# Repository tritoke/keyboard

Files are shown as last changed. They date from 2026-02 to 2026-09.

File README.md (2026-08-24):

# keyboard

This is my efforts towards making the exact keyboard entirely for fun.

Wants:
- Usable over USB or Bluetooth
- 65% with arrow keys, ISO enter and the four keys on the right

Progress:
- PCB (rev1 done)
- Case (freeCAD is kicking my ass)
- Firmware (I have some thoughts and that is all)

## PCB

Revision 1 of the PCB is now complete:

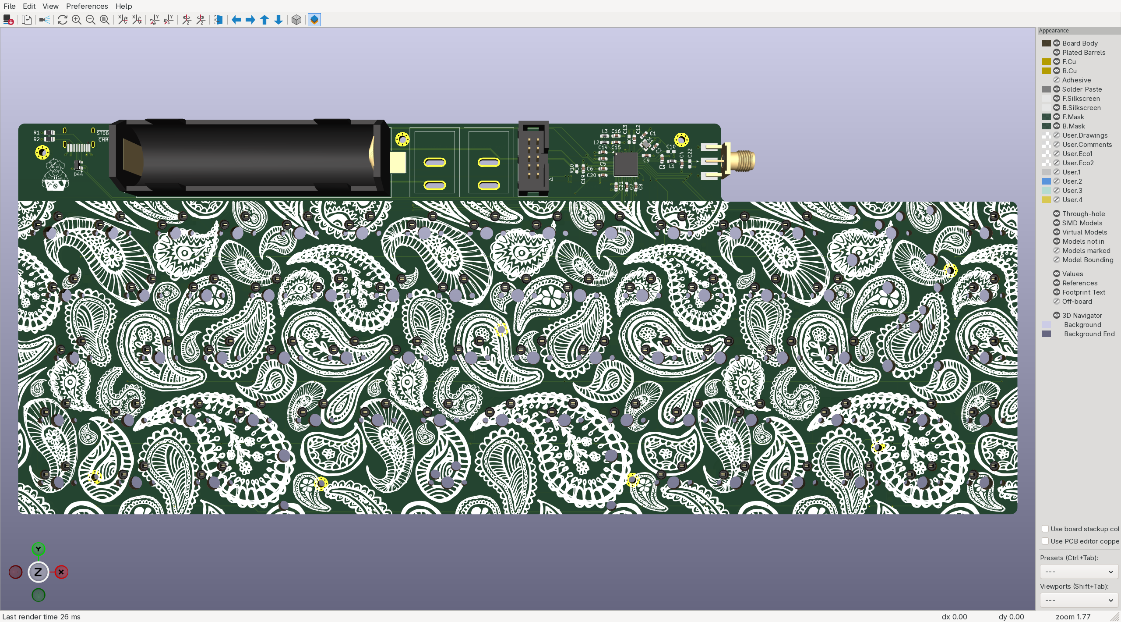
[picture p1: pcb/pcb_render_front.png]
A render in kicad of the front of the PCB


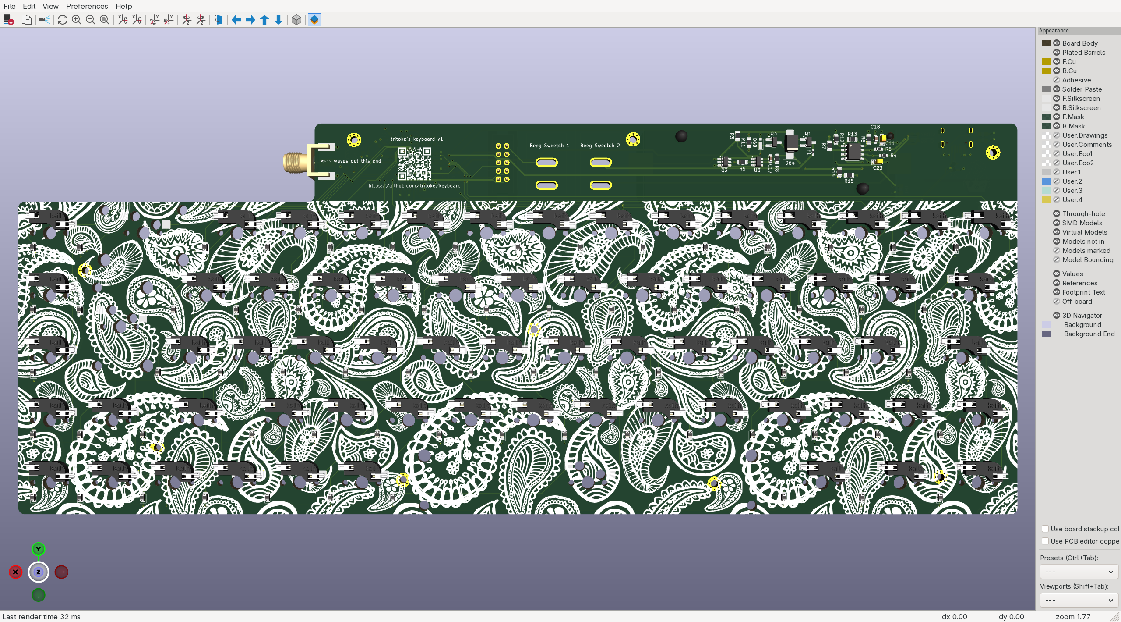
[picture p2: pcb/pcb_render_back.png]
A render in kicad of the back of the PCB


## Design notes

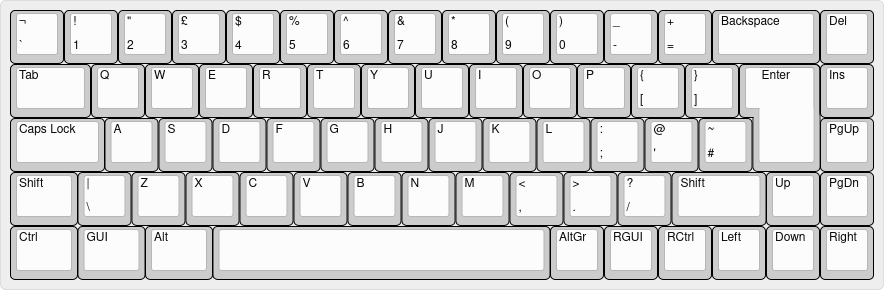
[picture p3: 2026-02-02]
assets/keyboard-layout.png

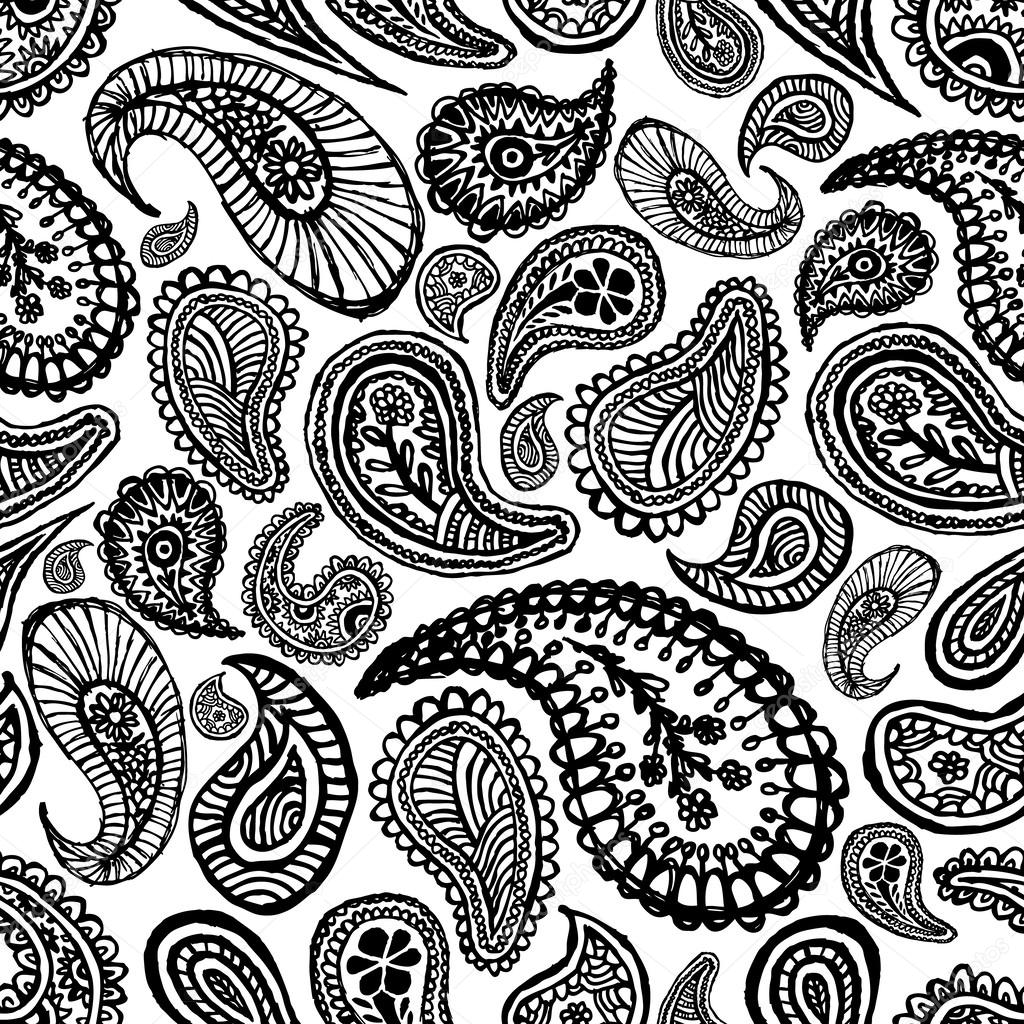
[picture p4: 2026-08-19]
pcb/paisley.png

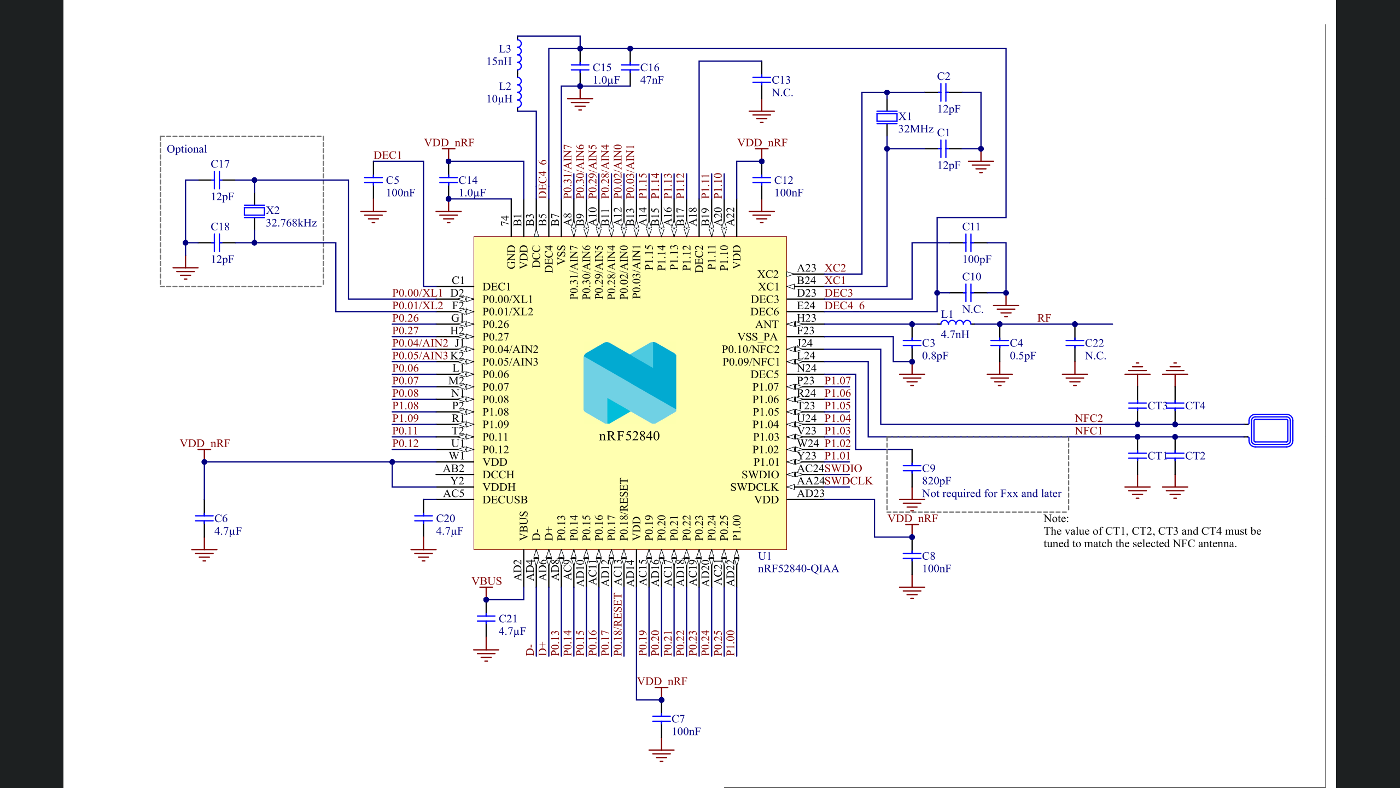
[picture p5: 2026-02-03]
pcb/datasheets/reccomended_power_stuff.png

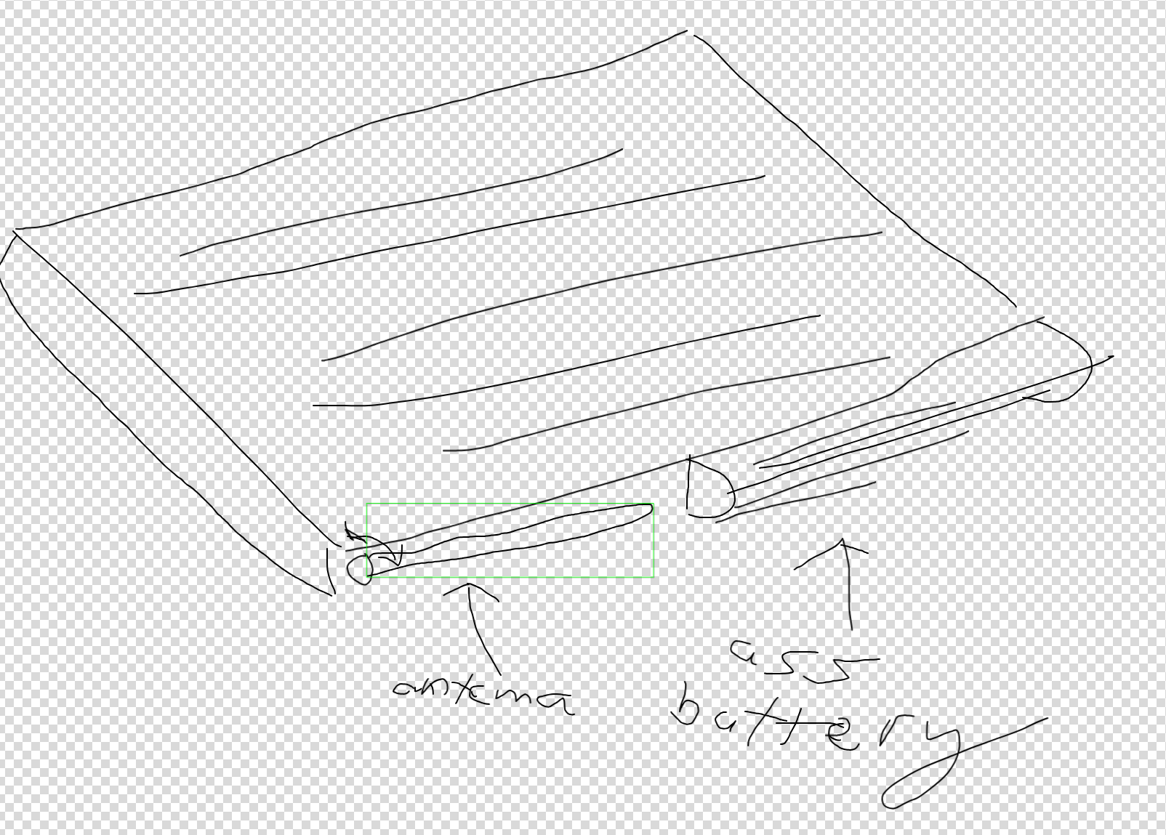
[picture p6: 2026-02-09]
case/the_vision.png

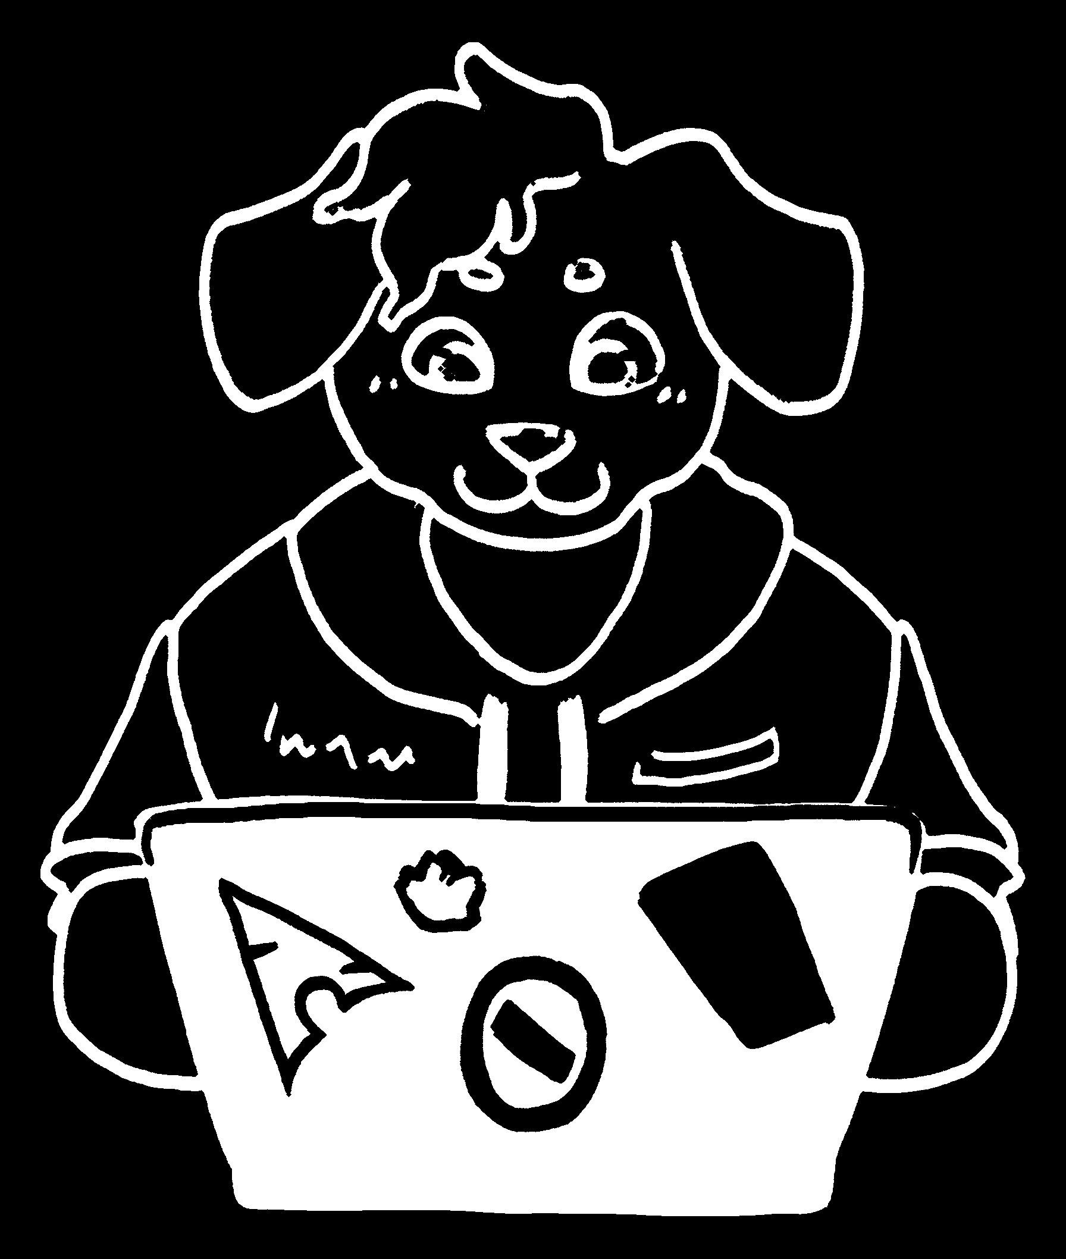
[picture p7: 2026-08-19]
pcb/out.png

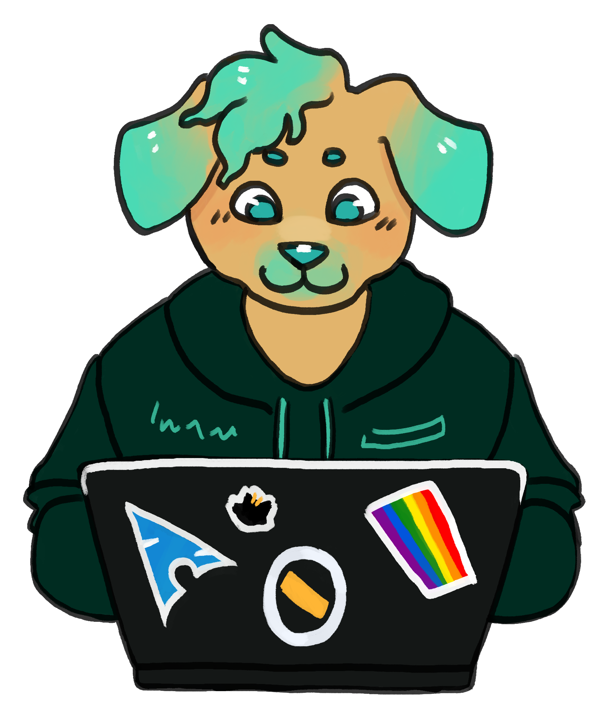
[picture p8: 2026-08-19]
pcb/pfp.png

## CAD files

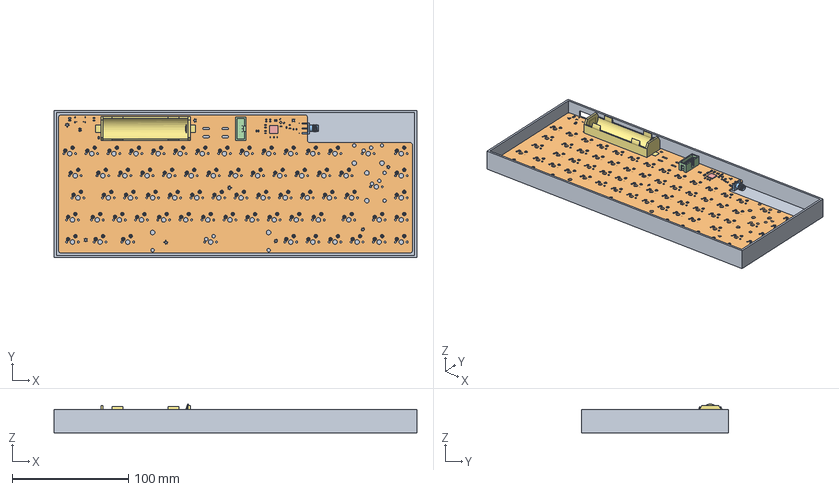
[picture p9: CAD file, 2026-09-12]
case/keyboard.FCStd
312.8 x 127.1 x 24.9 mm
Pcb_a2f5
SW_Hotswap_Kailh_cp x 66
SW_Hotswap_Kailh_cp001 x 66
SW_Hotswap_Kailh_cp002 x 66
C3_C_0603_1608Metric_d79f45b72fad x 21
L1_L_0603_1608Metric_e10466256f04 x 3
D65_LED_0603_1608Metric_e84010725488 x 2
R2_R_0805_2012Metric_39f1449e88a5 x 13
X1_Crystal_SMD_2016-4Pin_2.0x1.6mm_20b19a299bba
J3_SMA_Molex_73251-1153_EdgeMount_Horizontal_b3ee42c6dafb
J1_IDC_Header_2x05_P254mm_Vertical_1c1036271fdf
U1_Nordic_AQFN-73-1EP_7x7mm_P0.5mm_0fd2ffe46077
D44_SOT-143_3e3a47858965
Keystone_1042_1x18650
Keystone_1042_1x18651
Keystone_1042_1x18652
Keystone_1042_1x18653
Keystone_1042_1x18654
Keystone_1042_1x18655
Keystone_1042_1x18656
Keystone_1042_1x18657
Keystone_1042_1x18658
R10_R_0603_1608Metric_ecbf1ccea04d x 3
D33_D_0805_8298f5164884 x 69
Q2_SOT-23-6_e19e63b5ea5b x 2
Q1_SOT-23_cab122a346e8 x 2
U2_SOIC-8-1EP_3.9x4.9mm_P1.27mm_EP2.29x3mm_b853a6a36ce7
C23_CP_EIA_2012_15_AVX_P_0a915eff8187 x 2
D64_D_SMB_6a8cad30d266
F1_Fuse_0402_1005Metric_6239d229b4ee

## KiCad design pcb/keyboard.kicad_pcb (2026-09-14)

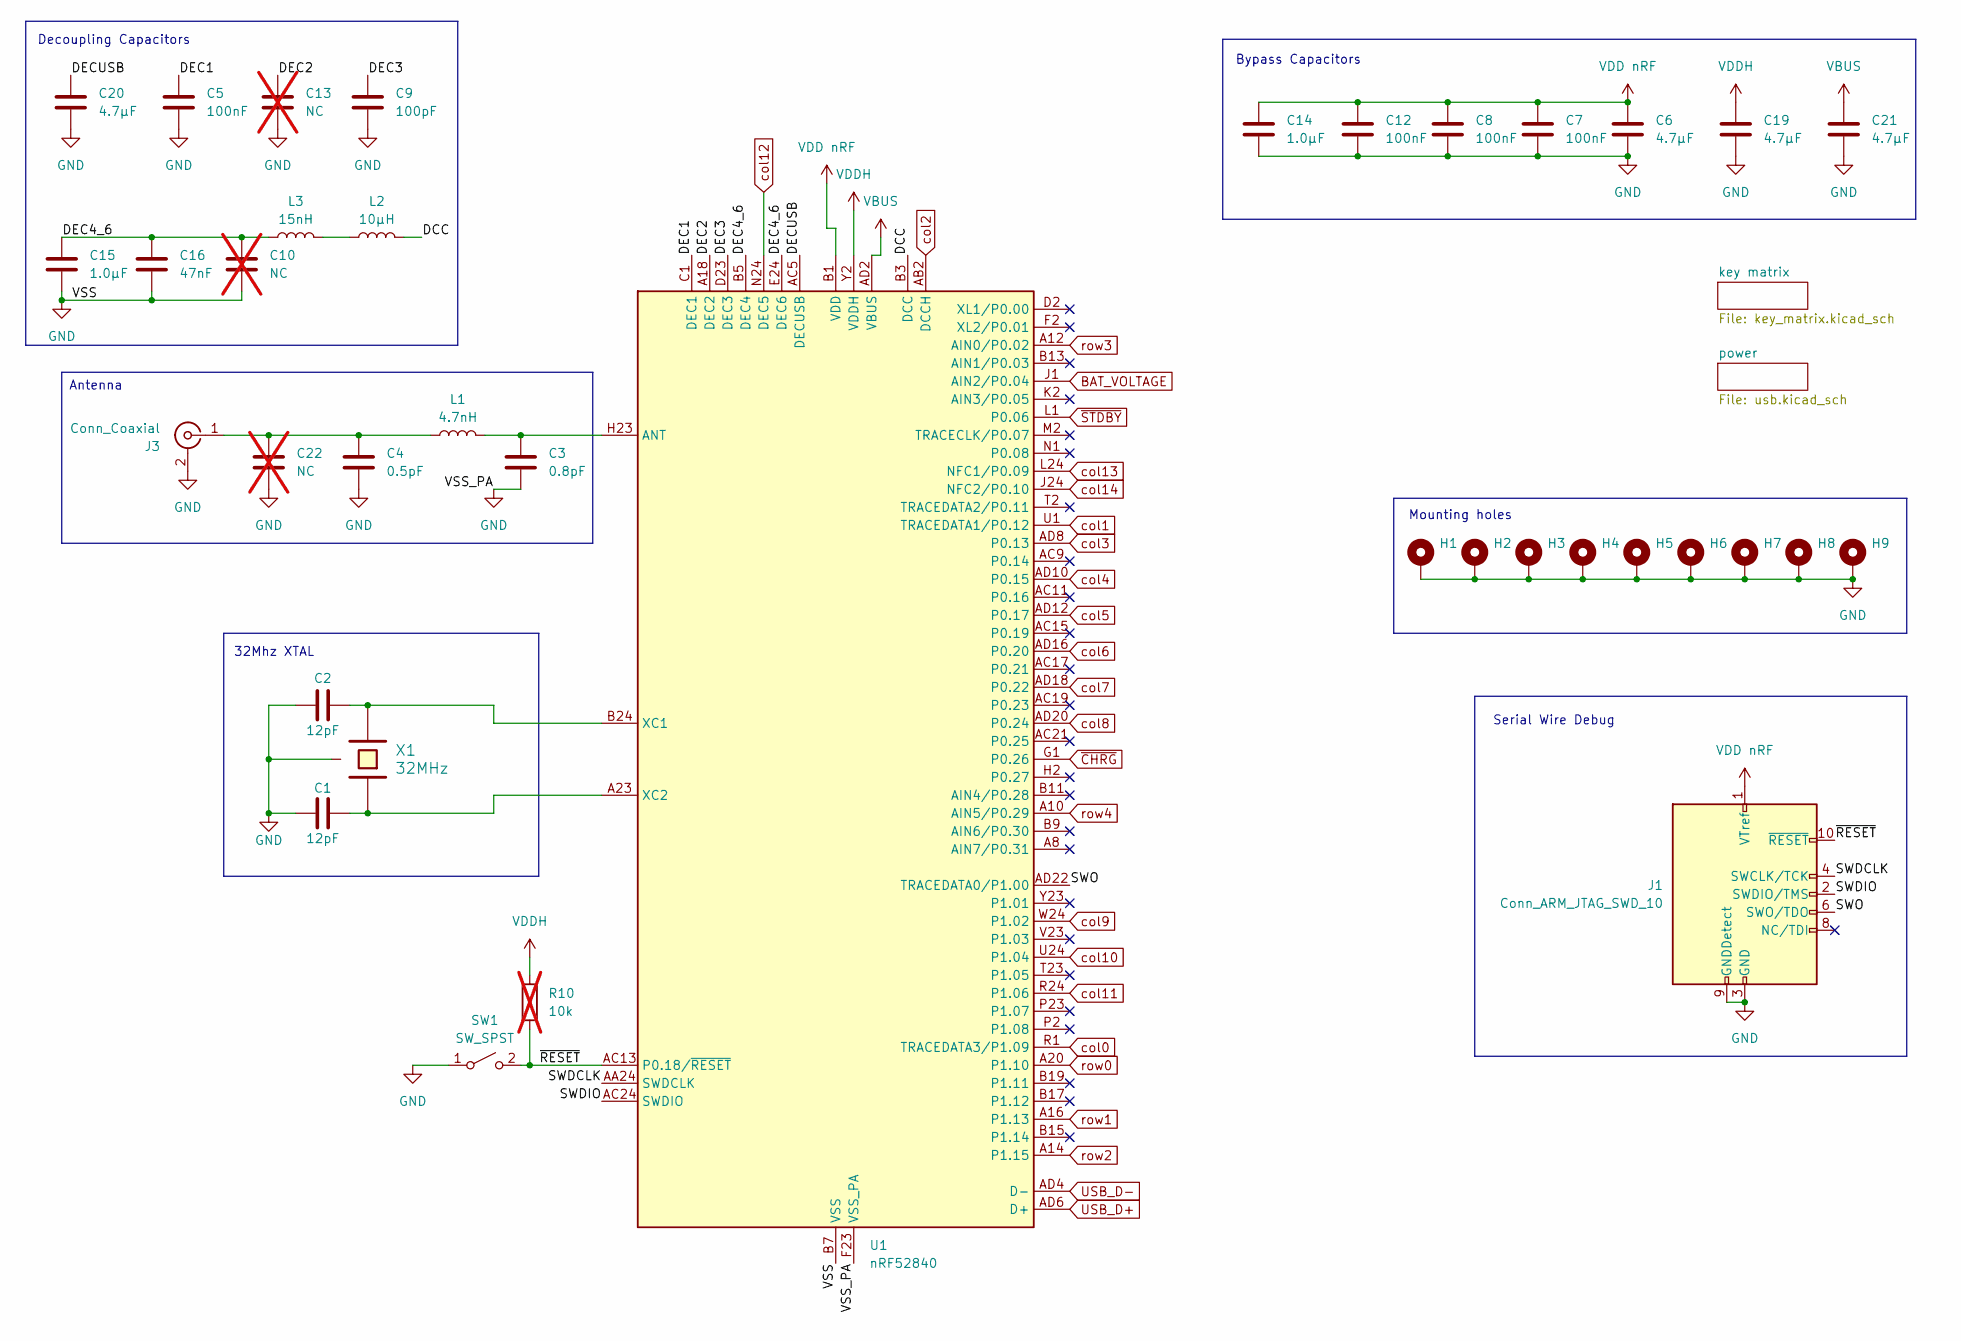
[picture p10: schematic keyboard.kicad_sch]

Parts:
C1, C2: 12pF; C_0603_1608Metric_Pad1.08x0.95mm_HandSolder
C3: 0.8pF; C_0603_1608Metric_Pad1.08x0.95mm_HandSolder
C4: 0.5pF; C_0603_1608Metric_Pad1.08x0.95mm_HandSolder
C5, C7, C8, C12: 100nF; C_0603_1608Metric_Pad1.08x0.95mm_HandSolder
C6, C19, C20, C21: 4.7µF; C_0603_1608Metric_Pad1.08x0.95mm_HandSolder
C9: 100pF; C_0603_1608Metric_Pad1.08x0.95mm_HandSolder
C10, C13, C22: NC; C_0603_1608Metric_Pad1.08x0.95mm_HandSolder; not fitted
C14, C15: 1.0µF; C_0603_1608Metric_Pad1.08x0.95mm_HandSolder
C16: 47nF; C_0603_1608Metric_Pad1.08x0.95mm_HandSolder
H1, H2, H3, H4, H5, H6, H7, H8, H9: MountingHole_Pad; MountingHole_2.2mm_M2_Pad_Via
J1: Conn_ARM_JTAG_SWD_10; IDC-Header_2x05_P2.54mm_Vertical
J3: Conn_Coaxial; SMA_Molex_73251-1153_EdgeMount_Horizontal_HandSolder
L1: 4.7nH; L_0603_1608Metric_Pad1.05x0.95mm_HandSolder
L2: 10µH; L_0603_1608Metric_Pad1.05x0.95mm_HandSolder
L3: 15nH; L_0603_1608Metric_Pad1.05x0.95mm_HandSolder
R10: 10k; R_0603_1608Metric_Pad0.98x0.95mm_HandSolder; not fitted
SW1: SW_SPST; Legion SS11
U1: nRF52840; Nordic_AQFN-73-1EP_7x7mm_P0.5mm
X1: 32MHz; Crystal_SMD_2016-4Pin_2.0x1.6mm_HandSolder

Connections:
/DCC: L2.2, U1.B3 (DCC)
/DEC1: C5.1, U1.C1 (DEC1)
/DEC2: C13.1, U1.A18 (DEC2)
/DEC3: C9.1, U1.D23 (DEC3)
/DEC4_6: C10.1, C15.1, C16.1, L3.1, U1.B5 (DEC4), U1.E24 (DEC6)
/DECUSB: C20.1, U1.AC5 (DECUSB)
/SWDCLK: J1.4 (SWCLK/TCK), U1.AA24 (SWDCLK)
/SWDIO: J1.2 (SWDIO/TMS), U1.AC24 (SWDIO)
/SWO: J1.6 (SWO/TDO), U1.AD22 (TRACEDATA0/P1.00)
/~RESET: J1.10 (~RESET), R10.2, SW1.2 (B), U1.AC13 (P0.18/~RESET)
BAT_VOLTAGE: U1.J1 (AIN2/P0.04); also elsewhere on the board
GND: C1.1, C2.1, C3.2, C4.2, C5.2, C6.2, C7.2, C8.2, C9.2, C10.2, C12.2, C13.2, C14.2, C15.2, C16.2, C19.2, C20.2, C21.2, C22.2, H1.1 (1_1), H2.1 (1_1), H3.1 (1_1), H4.1 (1_1), H5.1 (1_1), H6.1 (1_1), H7.1 (1_1), H8.1 (1_1), H9.1 (1_1), J1.3 (GND), J1.5 (GND), J1.9 (GNDDetect), J3.2 (Ext), SW1.1 (A), U1.B7 (VSS), U1.EP (VSS), U1.F23 (VSS_PA), X1.3; also elsewhere on the board
unnamed: C4.1, C22.1, J3.1 (In), L1.1
unnamed: L2.1, L3.2
unnamed: C3.1, L1.2, U1.H23 (ANT)
unnamed: C2.2, U1.B24 (XC1), X1.2
unnamed: C1.2, U1.A23 (XC2), X1.1
USB_D+: U1.AD6 (D+); also elsewhere on the board
USB_D-: U1.AD4 (D-); also elsewhere on the board
VBUS: C21.1, U1.AD2 (VBUS); also elsewhere on the board
VDD nRF: C6.1, C7.1, C8.1, C12.1, C14.1, J1.1 (VTref), U1.A22 (VDD), U1.AD14 (VDD), U1.AD23 (VDD), U1.B1 (VDD), U1.W1 (VDD)
VDDH: C19.1, R10.1, U1.Y2 (VDDH); also elsewhere on the board
col0: U1.R1 (TRACEDATA3/P1.09); also elsewhere on the board
col1: U1.U1 (TRACEDATA1/P0.12); also elsewhere on the board
col2: U1.AB2 (DCCH); also elsewhere on the board
col3: U1.AD8 (P0.13); also elsewhere on the board
col4: U1.AD10 (P0.15); also elsewhere on the board
col5: U1.AD12 (P0.17); also elsewhere on the board
col6: U1.AD16 (P0.20); also elsewhere on the board
col7: U1.AD18 (P0.22); also elsewhere on the board
col8: U1.AD20 (P0.24); also elsewhere on the board
col9: U1.W24 (P1.02); also elsewhere on the board
col10: U1.U24 (P1.04); also elsewhere on the board
col11: U1.R24 (P1.06); also elsewhere on the board
col12: U1.N24 (DEC5); also elsewhere on the board
col13: U1.L24 (NFC1/P0.09); also elsewhere on the board
col14: U1.J24 (NFC2/P0.10); also elsewhere on the board
row0: U1.A20 (P1.10); also elsewhere on the board
row1: U1.A16 (P1.13); also elsewhere on the board
row2: U1.A14 (P1.15); also elsewhere on the board
row3: U1.A12 (AIN0/P0.02); also elsewhere on the board
row4: U1.A10 (AIN5/P0.29); also elsewhere on the board
~CHRG: U1.G1 (P0.26); also elsewhere on the board
~STDBY: U1.L1 (P0.06); also elsewhere on the board

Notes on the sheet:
Bypass Capacitors
32Mhz XTAL
Mounting holes
Serial Wire Debug
Antenna
Decoupling Capacitors

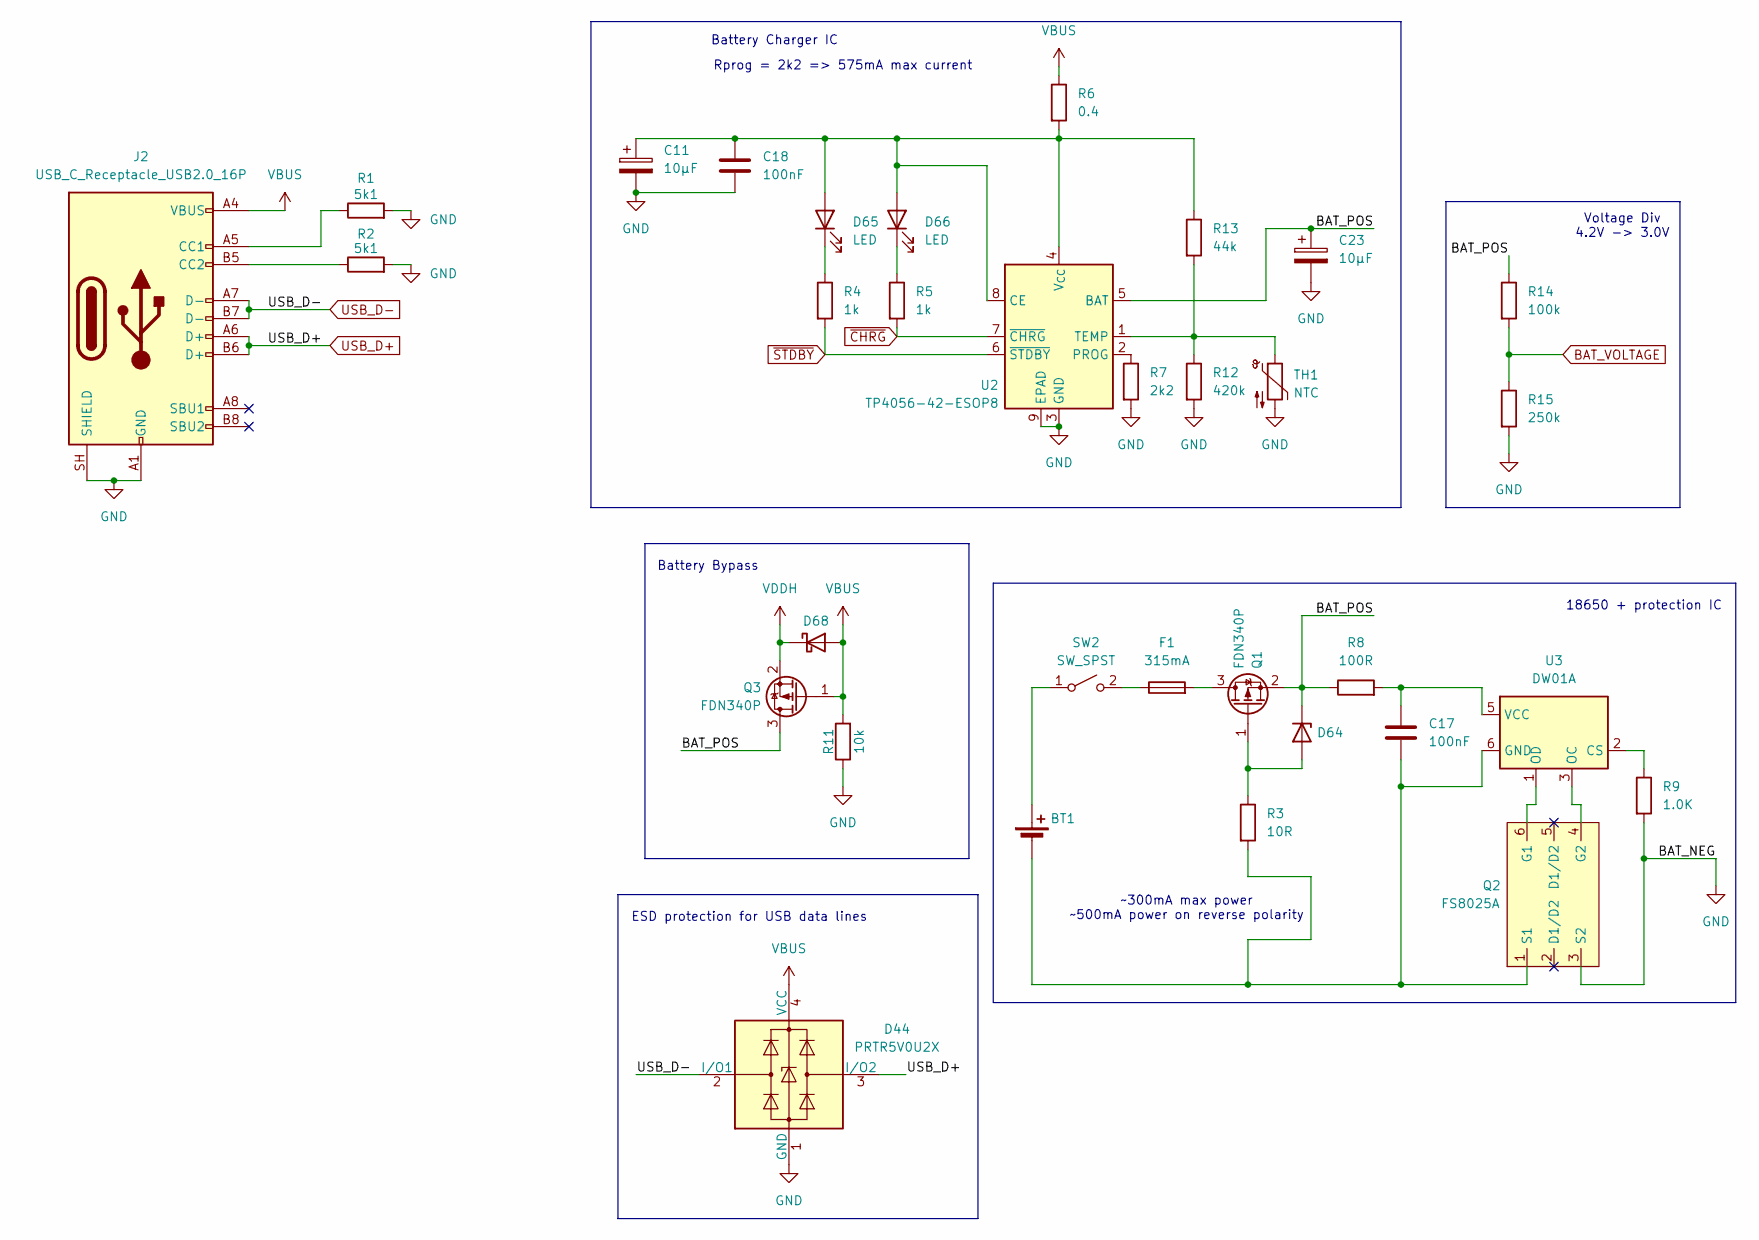
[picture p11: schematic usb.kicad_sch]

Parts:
BT1: Keystone 1042; BatteryHolder_Keystone_1042_1x18650
C11, C23: 10µF; CP_EIA-2012-15_AVX-P_HandSolder
C17, C18: 100nF; C_0603_1608Metric_Pad1.08x0.95mm_HandSolder
D44: PRTR5V0U2X; SOT-143
D64: 1SMB5918BT3G; D_SMB_Handsoldering
D65, D66: LED; LED_0603_1608Metric_Pad1.05x0.95mm_HandSolder
D68: MSS1P4-M3/89A; D_MicroSMP_LargeCathode
F1: 315mA; Fuse_0402_1005Metric_Pad0.77x0.64mm_HandSolder
J2: USB_C_Receptacle_USB2.0_16P; USB_C_Receptacle_G-Switch_GT-USB-7010ASV_handsolder_lmao.csv
Q1, Q3: FDN340P; SOT-23_Handsoldering
Q2: FS8025A; SOT-23-6_Handsoldering
R1, R2: 5k1; R_0805_2012Metric_Pad1.20x1.40mm_HandSolder
R3: 10R; R_0805_2012Metric_Pad1.20x1.40mm_HandSolder
R4, R5: 1k; R_0603_1608Metric_Pad0.98x0.95mm_HandSolder
R6: 0.4; R_0805_2012Metric_Pad1.20x1.40mm_HandSolder
R7: 2k2; R_0805_2012Metric_Pad1.20x1.40mm_HandSolder
R8: 100R; R_0805_2012Metric_Pad1.20x1.40mm_HandSolder
R9: 1.0K; R_0805_2012Metric_Pad1.20x1.40mm_HandSolder
R11: 10k; R_0805_2012Metric_Pad1.20x1.40mm_HandSolder
R12: 420k; R_0805_2012Metric_Pad1.20x1.40mm_HandSolder
R13: 44k; R_0805_2012Metric_Pad1.20x1.40mm_HandSolder
R14: 100k; R_0805_2012Metric_Pad1.20x1.40mm_HandSolder
R15: 250k; R_0805_2012Metric_Pad1.20x1.40mm_HandSolder
SW2: SW_SPST; Legion SS11
TH1: NTC; R_0805_2012Metric_Pad1.20x1.40mm_HandSolder
U2: TP4056-42-ESOP8; SOIC-8-1EP_3.9x4.9mm_P1.27mm_EP2.29x3mm
U3: DW01A; SOT-23-6

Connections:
/power/BAT_POS: C23.1, D64.1 (K), Q1.2 (S), Q3.3 (D), R8.1, R14.1, U2.5 (BAT)
BAT_VOLTAGE: R14.2, R15.1; also elsewhere on the board
GND: C11.2, C18.2, C23.2, D44.1 (GND), J2.A1 (GND), J2.A12 (GND), J2.B1 (GND), J2.B12 (GND), J2.SH (SHIELD), Q2.3 (S2), R1.2, R2.2, R7.2, R9.2, R11.1, R12.2, R15.2, TH1.2, U2.3 (GND), U2.9 (EPAD); also elsewhere on the board
unnamed: BT1.1 (+), SW2.1 (A)
unnamed: BT1.2 (-), C17.2, Q2.1 (S1), R3.2, U3.6 (GND)
unnamed: D64.2 (A), Q1.1 (G), R3.1
unnamed: C11.1, C18.1, D65.2 (A), D66.2 (A), R6.2, R13.1, U2.4 (V_{CC}), U2.8 (CE)
unnamed: D65.1 (K), R4.1
unnamed: D66.1 (K), R5.1
unnamed: J2.A5 (CC1), R1.1
unnamed: J2.B5 (CC2), R2.1
unnamed: F1.2, Q1.3 (D)
unnamed: Q2.6 (G1), U3.1 (OD)
unnamed: Q2.4 (G2), U3.3 (OC)
unnamed: F1.1, SW2.2 (B)
unnamed: R7.1, U2.2 (PROG)
unnamed: R12.1, R13.2, TH1.1, U2.1 (TEMP)
unnamed: R9.1, U3.2 (CS)
unnamed: C17.1, R8.2, U3.5 (VCC)
USB_D+: D44.3 (I/O2), J2.A6 (D+), J2.B6 (D+); also elsewhere on the board
USB_D-: D44.2 (I/O1), J2.A7 (D-), J2.B7 (D-); also elsewhere on the board
VBUS: D44.4 (VCC), D68.2 (A), J2.A4 (VBUS), J2.A9 (VBUS), J2.B4 (VBUS), J2.B9 (VBUS), Q3.1 (G), R6.1, R11.2; also elsewhere on the board
VDDH: D68.1 (K), Q3.2 (S); also elsewhere on the board
~CHRG: R5.2, U2.7 (~CHRG); also elsewhere on the board
~STDBY: R4.2, U2.6 (~STDBY); also elsewhere on the board

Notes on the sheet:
Voltage Div 4.2V -> 3.0V
Rprog = 2k2 => 575mA max current
18650 + protection IC
Battery Charger IC
ESD protection for USB data lines
~300mA max power ~500mA power on reverse polarity
Battery Bypass

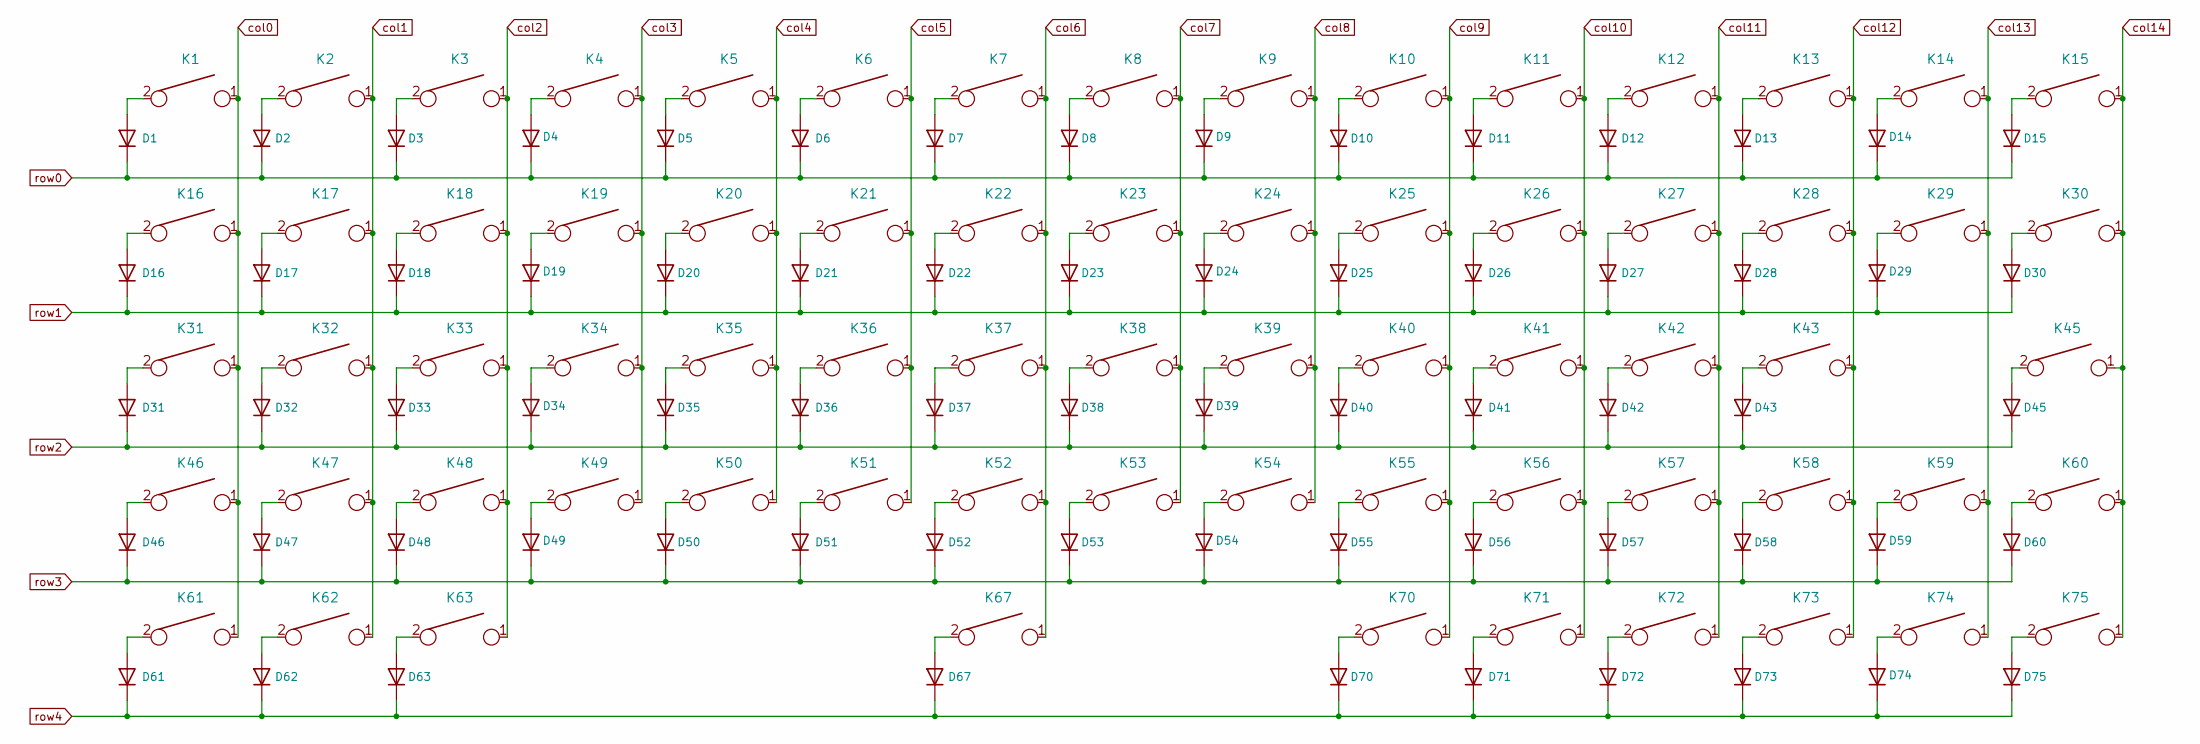
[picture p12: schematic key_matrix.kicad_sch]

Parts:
D1, D2, D3, D4, D5, D6, D7, D8, D9, D10, D11, D12, D13, D14, D15, D16, D17, D18, D19, D20, D21, D22, D23, D24, D25, D26, D27, D28, D29, D30, D31, D32, D33, D34, D35, D36, D37, D38, D39, D40, D41, D42, D43, D45, D46, D47, D48, D49, D50, D51, D52, D53, D54, D55, D56, D57, D58, D59, D60, D61, D62, D63, D67, D70, D71, D72, D73, D74, D75: D; D_0805_2012Metric_Pad1.15x1.40mm_HandSolder
K1, K2, K3, K4, K5, K6, K7, K8, K9, K10, K11, K12, K13, K15, K17, K18, K19, K20, K21, K22, K23, K24, K25, K26, K27, K28, K30, K32, K33, K34, K35, K36, K37, K38, K39, K40, K41, K42, K43, K45, K47, K48, K49, K50, K51, K52, K53, K54, K55, K56, K57, K59, K60, K70, K71, K72, K73, K74, K75: KEYSW; SW_Hotswap_Kailh_MX_1.00u
K14: KEYSW; SW_Hotswap_Kailh_MX_2.00u_Stabilised
K16, K46, K61, K62, K63: KEYSW; SW_Hotswap_Kailh_MX_1.25u
K29: KEYSW; SW_Hotswap_Kailh_MX_ISOEnter_Stabilised
K31, K58: KEYSW; SW_Hotswap_Kailh_MX_1.75u
K67: KEYSW; SW_Hotswap_Kailh_MX_6.25u_Stabilised

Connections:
unnamed: D1.2 (A), K1.2
unnamed: D2.2 (A), K2.2
unnamed: D3.2 (A), K3.2
unnamed: D4.2 (A), K4.2
unnamed: D5.2 (A), K5.2
unnamed: D6.2 (A), K6.2
unnamed: D7.2 (A), K7.2
unnamed: D8.2 (A), K8.2
unnamed: D9.2 (A), K9.2
unnamed: D10.2 (A), K10.2
unnamed: D11.2 (A), K11.2
unnamed: D12.2 (A), K12.2
unnamed: D13.2 (A), K13.2
unnamed: D14.2 (A), K14.2
unnamed: D15.2 (A), K15.2
unnamed: D16.2 (A), K16.2
unnamed: D17.2 (A), K17.2
unnamed: D18.2 (A), K18.2
unnamed: D19.2 (A), K19.2
unnamed: D20.2 (A), K20.2
unnamed: D21.2 (A), K21.2
unnamed: D22.2 (A), K22.2
unnamed: D23.2 (A), K23.2
unnamed: D24.2 (A), K24.2
unnamed: D25.2 (A), K25.2
unnamed: D26.2 (A), K26.2
unnamed: D27.2 (A), K27.2
unnamed: D28.2 (A), K28.2
unnamed: D29.2 (A), K29.2
unnamed: D30.2 (A), K30.2
unnamed: D31.2 (A), K31.2
unnamed: D32.2 (A), K32.2
unnamed: D33.2 (A), K33.2
unnamed: D34.2 (A), K34.2
unnamed: D35.2 (A), K35.2
unnamed: D36.2 (A), K36.2
unnamed: D37.2 (A), K37.2
unnamed: D38.2 (A), K38.2
unnamed: D39.2 (A), K39.2
unnamed: D40.2 (A), K40.2
unnamed: D41.2 (A), K41.2
unnamed: D42.2 (A), K42.2
unnamed: D43.2 (A), K43.2
unnamed: D45.2 (A), K45.2
unnamed: D46.2 (A), K46.2
unnamed: D47.2 (A), K47.2
unnamed: D48.2 (A), K48.2
unnamed: D49.2 (A), K49.2
unnamed: D50.2 (A), K50.2
unnamed: D51.2 (A), K51.2
unnamed: D52.2 (A), K52.2
unnamed: D53.2 (A), K53.2
unnamed: D54.2 (A), K54.2
unnamed: D55.2 (A), K55.2
unnamed: D56.2 (A), K56.2
unnamed: D57.2 (A), K57.2
unnamed: D58.2 (A), K58.2
unnamed: D59.2 (A), K59.2
unnamed: D60.2 (A), K60.2
unnamed: D61.2 (A), K61.2
unnamed: D62.2 (A), K62.2
unnamed: D63.2 (A), K63.2
unnamed: D67.2 (A), K67.2
unnamed: D70.2 (A), K70.2
unnamed: D71.2 (A), K71.2
unnamed: D72.2 (A), K72.2
unnamed: D73.2 (A), K73.2
unnamed: D74.2 (A), K74.2
unnamed: D75.2 (A), K75.2
col0: K1.1, K16.1, K31.1, K46.1, K61.1; also elsewhere on the board
col1: K2.1, K17.1, K32.1, K47.1, K62.1; also elsewhere on the board
col2: K3.1, K18.1, K33.1, K48.1, K63.1; also elsewhere on the board
col3: K4.1, K19.1, K34.1, K49.1; also elsewhere on the board
col4: K5.1, K20.1, K35.1, K50.1; also elsewhere on the board
col5: K6.1, K21.1, K36.1, K51.1; also elsewhere on the board
col6: K7.1, K22.1, K37.1, K52.1, K67.1; also elsewhere on the board
col7: K8.1, K23.1, K38.1, K53.1; also elsewhere on the board
col8: K9.1, K24.1, K39.1, K54.1; also elsewhere on the board
col9: K10.1, K25.1, K40.1, K55.1, K70.1; also elsewhere on the board
col10: K11.1, K26.1, K41.1, K56.1, K71.1; also elsewhere on the board
col11: K12.1, K27.1, K42.1, K57.1, K72.1; also elsewhere on the board
col12: K13.1, K28.1, K43.1, K58.1, K73.1; also elsewhere on the board
col13: K14.1, K29.1, K59.1, K74.1; also elsewhere on the board
col14: K15.1, K30.1, K45.1, K60.1, K75.1; also elsewhere on the board
row0: D1.1 (K), D2.1 (K), D3.1 (K), D4.1 (K), D5.1 (K), D6.1 (K), D7.1 (K), D8.1 (K), D9.1 (K), D10.1 (K), D11.1 (K), D12.1 (K), D13.1 (K), D14.1 (K), D15.1 (K); also elsewhere on the board
row1: D16.1 (K), D17.1 (K), D18.1 (K), D19.1 (K), D20.1 (K), D21.1 (K), D22.1 (K), D23.1 (K), D24.1 (K), D25.1 (K), D26.1 (K), D27.1 (K), D28.1 (K), D29.1 (K), D30.1 (K); also elsewhere on the board
row2: D31.1 (K), D32.1 (K), D33.1 (K), D34.1 (K), D35.1 (K), D36.1 (K), D37.1 (K), D38.1 (K), D39.1 (K), D40.1 (K), D41.1 (K), D42.1 (K), D43.1 (K), D45.1 (K); also elsewhere on the board
row3: D46.1 (K), D47.1 (K), D48.1 (K), D49.1 (K), D50.1 (K), D51.1 (K), D52.1 (K), D53.1 (K), D54.1 (K), D55.1 (K), D56.1 (K), D57.1 (K), D58.1 (K), D59.1 (K), D60.1 (K); also elsewhere on the board
row4: D61.1 (K), D62.1 (K), D63.1 (K), D67.1 (K), D70.1 (K), D71.1 (K), D72.1 (K), D73.1 (K), D74.1 (K), D75.1 (K); also elsewhere on the board

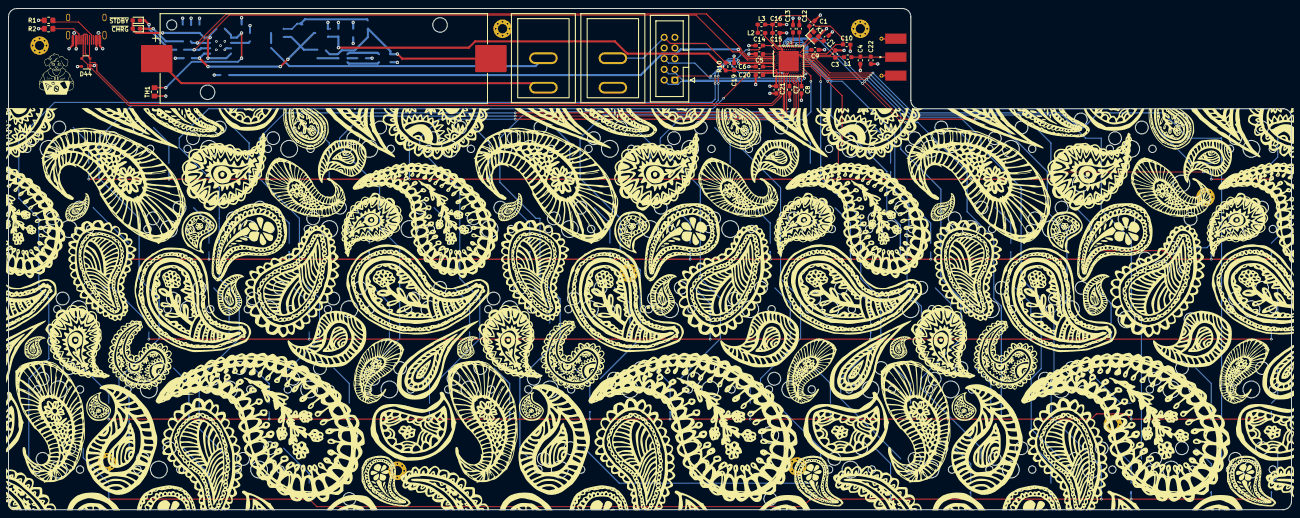
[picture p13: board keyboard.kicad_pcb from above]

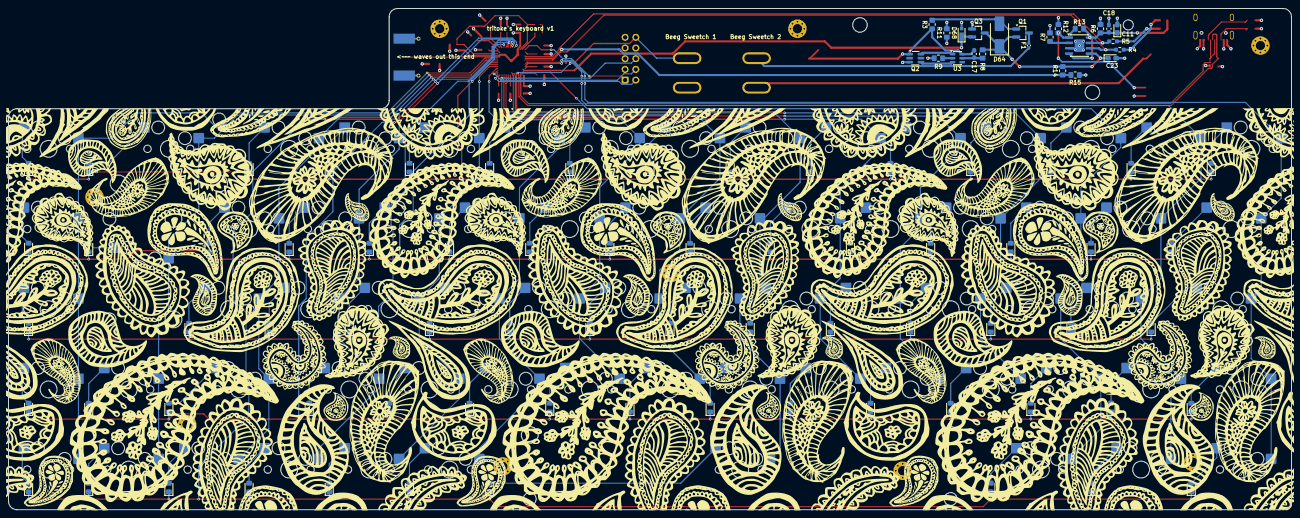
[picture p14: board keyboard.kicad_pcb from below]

Board: 4 copper layers, 304.8 x 119.1 mm, 208 parts (93 on the bottom side), 130 nets.

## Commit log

2026-02-03 Add submodules for kicad footprints and schematics
2026-02-03 Change uc footprint over to aQFN to access USB pins
    [keyboard.kicad_sch, usb.kicad_sch]
2026-02-09 Add case concept
2026-02-09 WIP: power / battery schematic
    [keyboard.kicad_sch, usb.kicad_sch]
2026-02-10 WIP: power / battery schematic 2
    [keyboard.kicad_sch, usb.kicad_sch]
2026-02-11 First version of power circuitry complete?
    [keyboard.kicad_sch, usb.kicad_sch]
2026-02-12 Add an on/off switch
    [usb.kicad_sch]
2026-02-12 Start assigning footprints
    [key_matrix.kicad_sch, keyboard.kicad_sch, usb.kicad_sch]
2026-02-13 Fix MOSFET orientation
    [usb.kicad_sch]
2026-02-13 Fix and complete keyswitch assignments
    [key_matrix.kicad_sch]
2026-02-18 Add battery protection IC
    [usb.kicad_sch]
2026-02-25 Finish power circuitry
    [keyboard.kicad_sch, usb.kicad_sch]
2026-03-22 Fill in some more components
    [key_matrix.kicad_sch, keyboard.kicad_sch, usb.kicad_sch]
2026-03-22 Pick a battery and add extra parts for TP4056
    [usb.kicad_sch]
2026-04-13 Update to kicad 10
    [key_matrix.kicad_sch, keyboard.kicad_pcb, keyboard.kicad_sch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]
2026-04-14 Add a stabilised footprint for a 6.25u key
    [key_matrix.kicad_sch]
2026-04-15 Add remaining stabilised keys
    [key_matrix.kicad_sch]
2026-04-15 AHH THE TRAIN IS GETTING IN
    [keyboard.kicad_pcb]
2026-04-29 Place all keys
    [keyboard.kicad_pcb]
2026-04-30 Fix some labels
    [keyboard.kicad_pcb]
2026-05-01 tinkering >:3
    [keyboard.kicad_pcb, keyboard.kicad_sch]
2026-06-16 Place all key matrix diodes
    [keyboard.kicad_pcb]
2026-06-16 Pick an NTC and calculate R1/R2
    [keyboard.kicad_pcb, usb.kicad_sch]
2026-06-18 idk, moved some bits round?
    [keyboard.kicad_pcb]
2026-06-24 Did a bunch of stuff lol
    [keyboard.kicad_pcb, keyboard.kicad_sch, usb.kicad_sch]
2026-06-26 Fixed switch footprint
    [keyboard.kicad_pcb]
2026-06-26 Did some stuff
    [keyboard.kicad_pcb, keyboard.kicad_sch, usb.kicad_sch]
2026-06-29 Fix diode placement
    [keyboard.kicad_pcb]
2026-06-29 Did a bunch of things!
    [keyboard.kicad_pcb, usb.kicad_sch]
2026-08-04 Improve clock placement and round corners
    [keyboard.kicad_pcb]
2026-08-06 Move some parts around lol
    [keyboard.kicad_pcb]
2026-08-07 Finish initial placement
    [keyboard.kicad_pcb]
2026-08-07 Add mounting points
    [keyboard.kicad_pcb, keyboard.kicad_sch]
2026-08-07 Add final hand solder footprints
    [keyboard.kicad_pcb, keyboard.kicad_sch]
2026-08-12 Started routing...
    [keyboard.kicad_pcb, keyboard.kicad_sch, usb.kicad_sch]
2026-08-13 idk lol
    [keyboard.kicad_pcb, keyboard.kicad_sch, usb.kicad_sch]
2026-08-16 Before I fuck it up
    [keyboard.kicad_pcb, keyboard.kicad_sch, usb.kicad_sch]
2026-08-16 Really nearly there with routing!
    [keyboard.kicad_pcb]
2026-08-16 Remove the hole in the middle of the board
    [keyboard.kicad_pcb]
2026-08-17 In case I fuck it up
    [keyboard.kicad_pcb, keyboard.kicad_sch]
2026-08-17 Finish initial routing
    [keyboard.kicad_pcb, keyboard.kicad_sch]
2026-08-17 voltage divider bits?
    [keyboard.kicad_sch, usb.kicad_sch]
2026-08-17 Add ~{CHRG} / ~{STDBY} detect + voltage div
    [keyboard.kicad_pcb, usb.kicad_sch]
2026-08-18 Address initial comments
    [keyboard.kicad_pcb]
2026-08-18 Address DRC violations
    [keyboard.kicad_pcb]
2026-08-18 I got the PCB into freecad, gg
    [keyboard.FCStd]
2026-08-19 Fuck around with silkscreen stuff
    [key_matrix.kicad_sch, keyboard.kicad_pcb]
2026-08-19 Make pfp higher res
    [keyboard.kicad_pcb]
2026-08-19 Paisley front / back pattern :D
    [keyboard.kicad_pcb]
2026-08-20 Make text a bit bigger
    [keyboard.kicad_pcb]
2026-08-21 Add QR code link to repo
    [keyboard.kicad_pcb]
2026-09-10 Align mounting holes to 1mm offsets
    [keyboard.kicad_pcb]
2026-09-10 Add first non-shit revision of the case
    [keyboard.FCStd]
2026-09-11 Add hole for USB-C port
    [keyboard.FCStd]
2026-09-12 Link dimension of all mounting holes
    [keyboard.FCStd]
2026-09-14 Re-pour planes and set inner layers as power planes
    [keyboard.kicad_pcb]
2026-09-14 Add teardrop on reset pin via
    [keyboard.kicad_pcb]
